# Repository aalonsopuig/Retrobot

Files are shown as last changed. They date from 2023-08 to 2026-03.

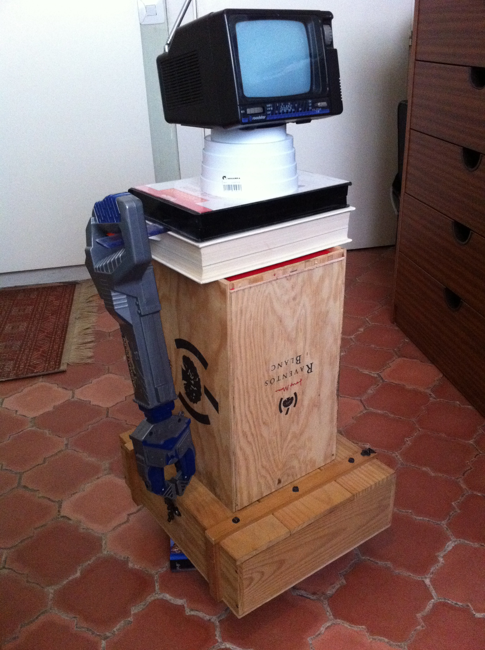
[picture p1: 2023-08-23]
Media/Imagen 343.jpg

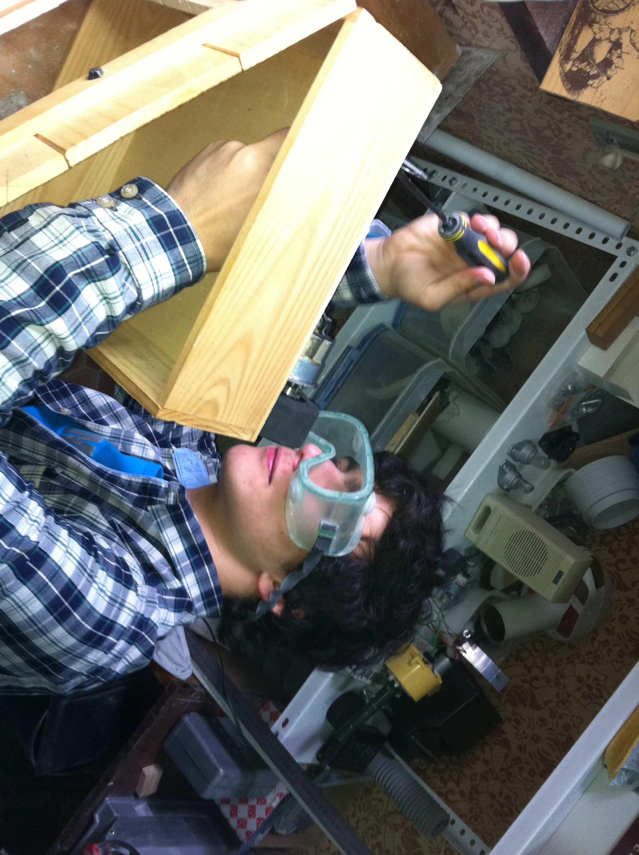
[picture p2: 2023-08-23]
Media/Imagen 345.jpg

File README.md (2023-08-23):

# Retrobot
 Por Alejandro Alonso y Manuel Alonso. 
 Julio 2011. 
 
Este fue un robot que hice para divertirme con mi sobrino. El objetivo era construir un robot con productos de principios de los 80. Para ello conseguimos un ordenador de los años 80 (Sinclair ZX-81) y otros componentes de eBay.
El robot pudo moverse, reproducir algunas canciones de esa época (grabadas en cinta de cassette y bailar mientras agitaba una maraca con su brazo izquierdo. También tenía un brazo derecho con una pinza extensible.
Fue presentado por primera vez en Campus Party 2011, evento que se realizaba en Valencia (España) para jóvenes aficionados a las tecnologías.

Retrobot_noticia

El centro del robot es un ordenador Sinclair ZX-81 original de los años 80, al cual se le ha conectado una tarjeta llamada interfaz (ExpansionCard) de diseño mío. Esta tarjeta contiene un microcontrolador Microchip PIC16F876, se conecta al puerto de expansión (bus) del ZX81 y permite a este acceder a todos los dispositivos del robot vía puerto I2C, así como mover los diferentes motores y actuadores del robot gracias a un driver incorporado en la tarjeta interfaz (ExpansionCard)
Nota: En el estado actual del proyecto, la tarjeta de interfaz está programada para controlar todo el robot y no hace de interfaz. Por tanto el software que se incluye en este repositorio solo hace esta función y el ZX81 no realiza ninguna función. Esto se debe a que el deseo de mostrar el robot moviéndose en Campus Party hizo que tuviese que recortar los tiempos, consiguiendo que el robot se moviese, pero sin conseguir el objetivo final, que era controlar el robot desde el ZX81 (objetivo pendiente que quizá algún día me anime a hacer)
Este es el el esquema general del robot:

Retrobot_aquitectura

Es este video puede verse el robot en acción en CampusParty 2011: https://www.youtube.com/watch?v=pIfZhs_rKEg

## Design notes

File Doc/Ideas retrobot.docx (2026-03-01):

# Ideas retrobot

Monitor es la cabeza

Zx81 el pecho

Muchas luces de colores

Brazo robotico

Sensores todo nada de infrarrojos distancia o pir

Base movil con ruedas y rueda loca

Si conseguimos sacar un puerto serie o I2C podriamos comunicarnos con una skypic plus o la que sea para enviarla ordenes y que ella se ocupe de comunicar con todas las funciones digitales o analogicas del cuerpo. Claro que entonces no se justifica tener un zx81

Ver los apuntes que tengo sobre los dos robots construidos con un zx81

Usar solo componentes existentes como tarde en los años 90

Usar sensores sharp GP2D15 fijado a 24cm. 15€

Usar sensor PIR delante pero metido en tubo para detectar una persona delante y hablar. 9€

Si hacemos una tarjeta interfaz i2c, podriamos poner montones de sensores conectados, tales como el capacitivo, mejores sensores de distancias, drivers, etc

Robot social que se acerca a personas y les dice cosas (usar tarjeta de voz digitalizada que tengo) como la temperatura que hace, si ha bebido o las caricias detectadas. En pantalla mostraria informacion escrita o expresiones emocionales

Para el I2C podemos usar un chip PCF8584. Más datos aquí: http://www.rwapservices.co.uk/ZX80_ZX81/forums/i2c-t412.html

Tarjeta conectada al ZX81 con el adaptador I2C, expansor de puertos, driver para luces, control servos, regulador de tensión, conversor A/D y sensor temperatura

Maracas

Iluminacion azul zx81 desde el interior del cuello

Antenas luminosas de Manolo para poner fuera de cascos

Efecto fibra de carbono

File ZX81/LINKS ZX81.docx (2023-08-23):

# LINKS ZX81

- Blog: http://www.elspectrumhoy.es
- Generador de WAVs: http://www.zx81stuff.org.uk/zx81/tapeutils/overview.html
- Soft, carátulas, pantallas, etc: http://www.zx81stuff.org.uk/zx81/indexframes.html
- Soft a tope: http://www.imarshall.karoo.net/zx81/
- Emuladores y .p files: http://www.zx81.nl/
- Varios en wav: http://personales.com/espana/alicante/todoa8bits/sinclair_CARGA.htm
- Manuales y documentos para parar un tren: http://www.worldofspectrum.org/documentation.html
- Solución video negro con televisores modernos: http://www.speccy.org/trastero/cosas/JL/zx81(2)/ZX81-video.html
- Inversor de video: http://www.user.dccnet.com/wrigter/index_files/zxinverter.htm
- Sacar la línea de video compuesto: http://www.zonadepruebas.com/modules/newbb/viewtopic.php?topic_id=11496&forum=2&post_id=112436
- Mucho soft gráfico: http://www.pictureviewerpro.com/hosting/zx81/fredn.htm
- Ingente info de hardware y soft: http://k1.dyndns.org/Vintage/Sinclair/80/Sinclair%20ZX81/
- ZX81 Speech synthesis: http://web.inter.nl.net/hcc/davies/mvzx81.html
- Sobre el conector para módulos externos. Este es el 5645169-2 para ISA, pero es compatible cortándolo: http://ie.farnell.com/edac/395-098-520-350/card-edge-connector-socket-98pos/dp/5389781, http://ca.digikey.com/1/1/2063590-conn-sec-ii-49pos-100-c-l-5645169-2.html, http://www.almita-connectors.com/connector/isa-connectors.html, http://www.kemax.com.tw/detail/284166/284166.html, http://parts.digikey.ca/1/1/107613-conn-sec-ii-30pos-100c-l-1-530843-8.html

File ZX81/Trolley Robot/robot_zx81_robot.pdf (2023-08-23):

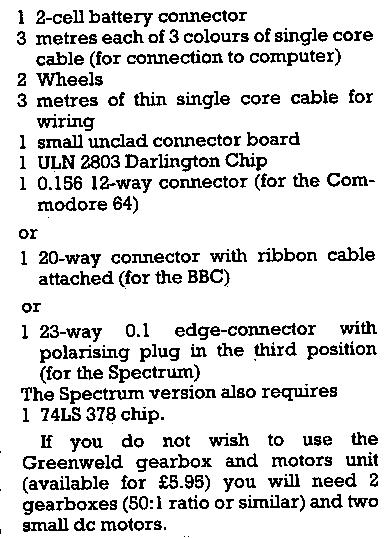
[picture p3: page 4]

Commodore:

10 POKE 59459,255: PO=59471: REM PET 10 POKE 56579,255: PO=56577: REM CBM64 10 POKE 37138,255: PO=37136: REM VIC20 20 DIM B(100), T(100)
30 N=0: TI$="000000"
40 POKE PO, 0
100 GET A$
110 IF A$="" THEN 100
120 IF A$=" " THEN K=0
130 IF A$="R" THEN K=1
140 IF A$="L" THEN K=2
150 IF A$="F" THEN K=3
160 IF A$="G" THEN 300
170 N=N+1: IF N>100 THEN 300 180 B(N)=K
190 T(N)=TI
200 POKE PO,0
220 FOR J=1 TO 200: NEXT
230 POKE PO,K
240 GOTO 100
300 TI$="000000"
310 POKE PO,0
320 FOR M=1 TO N
330 IF TI<T(M) THEN 330
340 POKE PO,0
350 FOR J=1 TO 200: NEXT
360 POKE PO,B(M)
370 NEXT M

BBC:

10 DIM B(100)
20 DIM T(100)
30 N=0: TIME=0
40 J=0: K=0
50 PORT=&FE60: ?&FE62=3
100 A$=INKEY$(0)
130 IF A$="" THEN 100
140 IF A$=" " THEN K=0
150 IF A$="L" THEN K=2
160 IF A$="R" THEN K=1
170 IF A$="F" THEN K=3
180 IF A$="G" THEN 300
190 N=N+1
200 B(N)=K•
210 T(N)=TIME
220 ?PORT=0
230 J=INKEY(25)
240 ?PORT=K
260 GOTO 100
300 TIME=0
310 FOR M=1 TO N
320 REPEAT UNTIL TIME > T(M) 330 ?PORT=0
340 K=INKEY(25)
350 ?PORT=B(M)
360 NEXT M

Sinclair:

10 DIM b(100)
20 DIM t(100)
30 LET i=0: LET n=0: LET j=0: LET k=0 100 LET a$=INKEY$
110 LET i=i+1
120 IF i<j THEN GO TO 100
130 IF a$="" THEN GO TO 100 140 IF a$=" " THEN LET k=0 150 IF a$="l" THEN LET k=2 160 IF a$="r" THEN LET k=1 170 IF a$="f" THEN LET k=3 180 IF a$="g" THEN GO TO 300 190 LET n=n+1
200 LET b(n)=k
210 LET t(n)=i
220 OUT 255,0
230 FOR j=1 TO 100: NEXT j 240 OUT 255,k
250 LET j=1

260 GO TO 100
300 LET i=0
310 FOR m=1 TO n
320 FOR j=1 TO t(m): NEXT j 330 OUT 255,0
340 FOR j=1 TO 100: NEXT j 350 OUT 255,b(m)
360 NEXT m
370 OUT 255,0

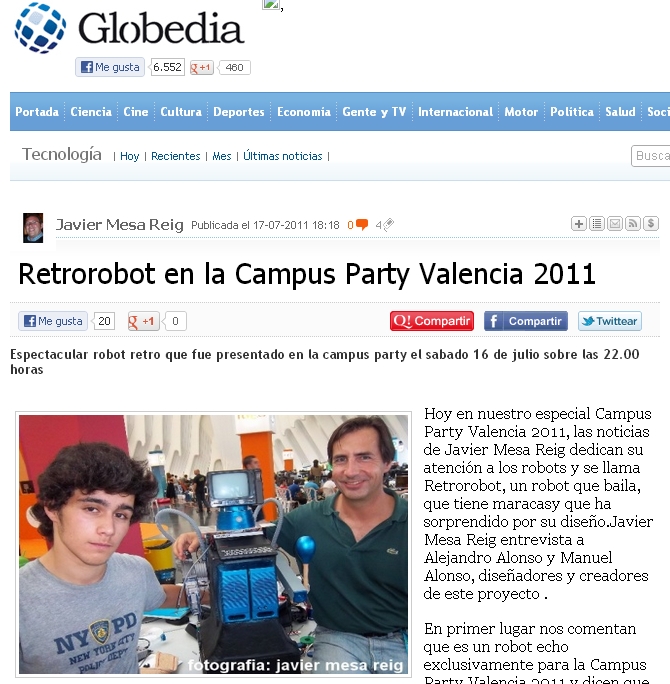
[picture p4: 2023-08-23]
Media/Retrobot_noticia.jpg

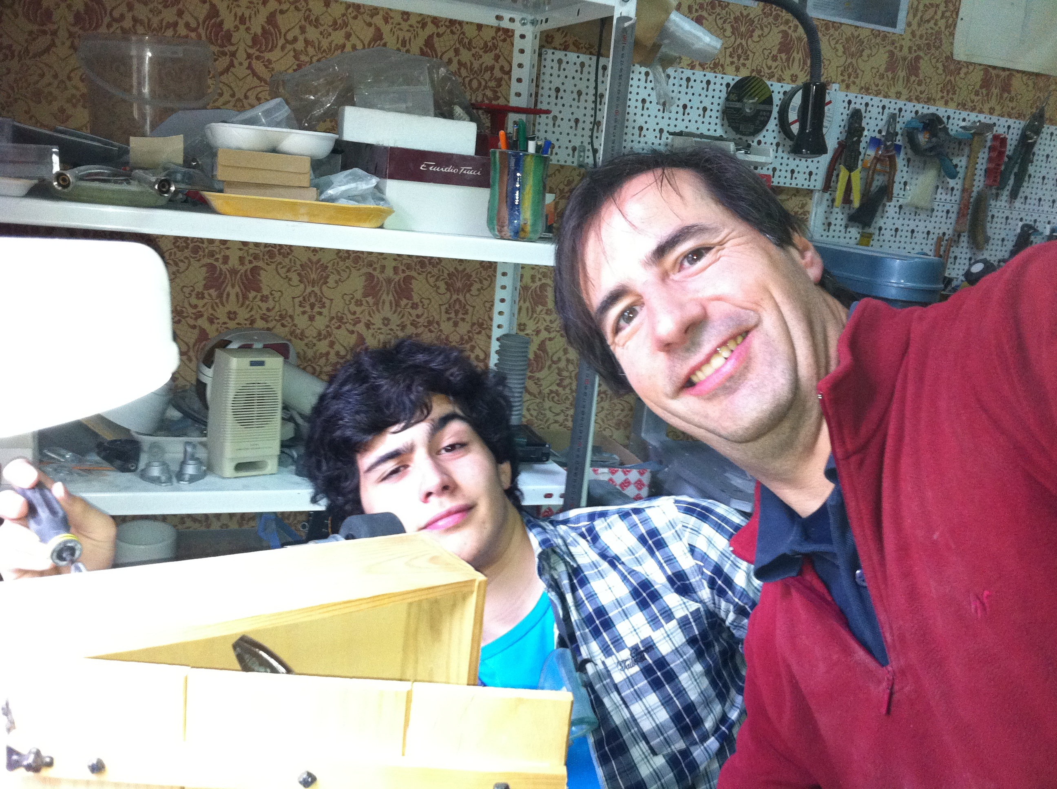
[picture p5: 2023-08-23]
Media/Imagen 346.jpg

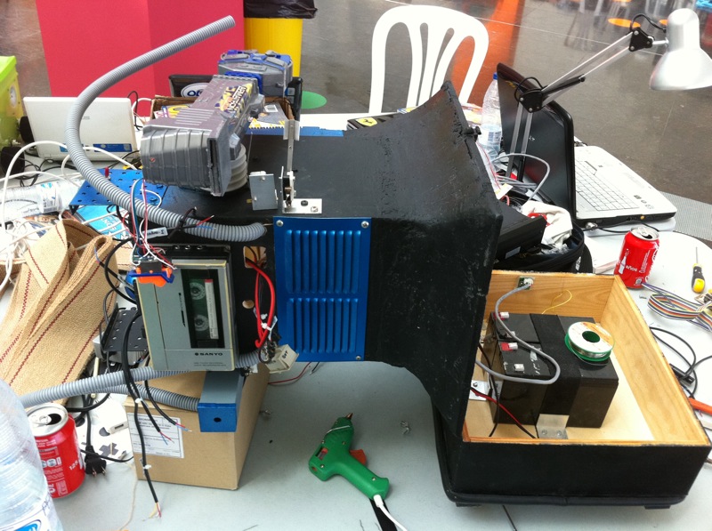
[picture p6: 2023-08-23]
Media/Foto 16-07-11 15 34 29.jpeg

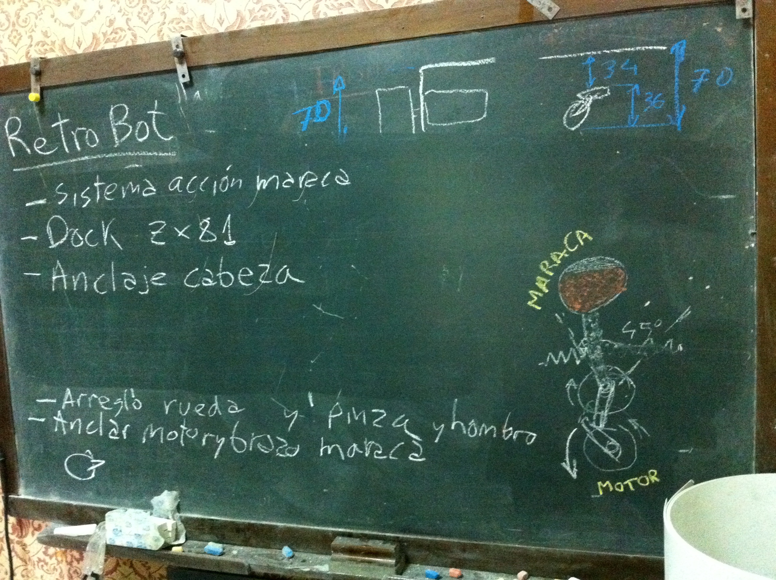
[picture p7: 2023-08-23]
Media/Imagen 130.jpg

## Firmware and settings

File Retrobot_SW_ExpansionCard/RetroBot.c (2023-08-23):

/*
PROGRAM:    RetroBot
DEVELOPER:  LIEBANA Design
DATE:       July 2011
Purpose:    This program is loaded in the ZX81 Expansion Card
            and control the interface.

Pinout:
RA0   IN    Not connected
RA1   OUT   ZX81 Wait signal
RA2   IN    ZX81 Direction of data 
RA3   OUT   Relay control
RA4   IN    Not connected
RA5   IN    PIR signal
RB0   IN    ZX81 ready signal      
RB1   I/O   Data Line 1 
RB2   I/O   Data Line 2
RB3   I/O   Data Line 3
RB4   I/O   Data Line 4
RB5   I/O   Data Line 5
RB6   I/O   Data Line 6
RB7   I/O   Data Line 7
RC0   IN    Not connected   
RC1   OUT   PWM2 for motors   
RC2   OUT   PWM1 for motors 
RC3         I2C. SCL
RC4         I2C. SDA
RC5   I/O   Data Line 0
RC6   OUT   Led
RC7   IN    Not connected

I/O Expansion Port Pinout:

A0    OUT   S1M1
A1    OUT   S2M1
A2    OUT   S1M2
A3    OUT   S2M2
A4    OUT   S1M3
A5    OUT   S2M3
A6    OUT   S1M4
A7    OUT   S2M4 
B0    OUT   S1M5
B1    OUT   S2M5
B2    OUT   S1M6
B3    OUT   S2M6
B4    OUT   S1M7
B5    OUT   S2M7
B6    OUT   S1M8
B7    OUT   S2M8


*/
// LIBRARIES
#include "RetroBot.h"
#include "LM75.h"             //Library for LM75 I2C Temperature Sensor 
#include "MCP23016.h"         //MCP23016 Chip (16 bit IO expander via I2C)
#include "SRF02.h"            //SRF02 Device (Sonar via I2C)

//I2C address
#DEFINE  LM75Address      0x9E  //Temperature sensor
#DEFINE  SRF02Address     0xE0  //Sonar sensor

//Pins assignment
#DEFINE  ZX81_WAIT       PIN_A1   //Active low. stop ZX81 clock during a transfer
#DEFINE  ZX81_DIR        PIN_A2   //Data dir. 1:ZX81->ExpCard, 0:ExpCard->ZX81
#DEFINE  Relay           PIN_A3   //Relay control
#DEFINE  PIR             PIN_A5   //PIR signal
#DEFINE  ZX81_READY      PIN_B0   //Indicate ZX81 is ready for a read or write
#DEFINE  DataLine0       PIN_C5   //Data line 0
#DEFINE  LED             PIN_C6   //Test led

//Motors control
#DEFINE  FORWARD         255      //Forward for motors
#DEFINE  BACKWARD          0      //Backward for motors
#DEFINE  STOP            128      //Stop for motors
#DEFINE  ACTIVATE          0      //ACTIVATE for motors
#DEFINE  OPEN            255      //OPEN for motors
#DEFINE  CLOSE             0      //CLOSE for motors
#DEFINE  UP              255      //Move up for motors
#DEFINE  DOWN              0      //Move down for motors

#DEFINE  MaxDuty 800     //Maximum value of Duty Cycle (100%)
#DEFINE  MinDuty 200     //Duty were the motor stops for sure

//Motor assignment
#DEFINE  Maraca            1      //Motor assigned to Maraca
#DEFINE  Hand_R            2      //Motor assigned to Hand of right arm
#DEFINE  Arm_R             3      //Motor assigned to right arm
#DEFINE  Light_R           4      //Motor assigned to light of right arm
#DEFINE  Wheel_R           5      //Motor assigned to right wheel
#DEFINE  Wheel_L           6      //Motor assigned to left wheel
#DEFINE  Shoulder_R        7      //Motor assigned to shoulder of right arm
#DEFINE  Shoulder_L        8      //Motor assigned to shoulder of left arm


//Counters
#DEFINE  MaxCounters    2     //Number of multipurpose counters
#DEFINE  AutoNavFwd     0     //counter for allowing forward movement
#DEFINE  Dance          1     //counter for dance times

#DEFINE  MaxAutoNavFwd   381     //x13.1= 5s aprox
#DEFINE  MaxDance        763     //x13.1= 10s aprox


byte  Temperature=0;             //Temperature of the card
byte  Distance=0;                //Value in cm of distance to obstacle 8bit
int1  PIRStatus=FALSE;           //Status of PIR sensor

int1  AutoNavMode=FALSE;      //Indicate if auto navigation mode is active
int16 Counter[MaxCounters];         //Multipurpose counters incremented by interrupt

int16  i;                            //Used for local FOR loops



#INT_TIMER3
//Timer3 Interrupt. Used for several multipurpose counters Counter[]
//overflows every 13.1ms incrementing all counters by 1
void Timer3_isr() 
{
   byte NumCounter;

   for(NumCounter=0;NumCounter<MaxCounters;NumCounter++)
      Counter[NumCounter]++;
}


void InitGeneralPurposeCounters() 
//Put all general purpose counters to 0
{
   byte NumCounter;

   for(NumCounter=0;NumCounter<MaxCounters;NumCounter++)
      Counter[NumCounter]=0;
}   

void Blink (byte blinks)
//Blinks card led
{
   byte i;
   for(i=1;i<=blinks;i++) {
      output_high(LED);
      delay_ms(100);
      output_low(LED);
      delay_ms(100);              
   }
}


void SetMotor (byte MotorNum, Direction)
//Control the direction of the 8 motors
//Direction 128:Stop, >128:Forward, <128:backwards
{
   switch (MotorNum) {
      case 1:
         if(Direction<128){
            MCP23016_output_high (MCP23016_PIN_A0);
            MCP23016_output_low  (MCP23016_PIN_A1);
         }
         if(Direction>128){
            MCP23016_output_low  (MCP23016_PIN_A0);
            MCP23016_output_high (MCP23016_PIN_A1);
         }
         if(Direction==128){
            MCP23016_output_low (MCP23016_PIN_A0|MCP23016_PIN_A1);         
         }
         break;
      case 2:
         if(Direction<128){
            MCP23016_output_high (MCP23016_PIN_A2);
            MCP23016_output_low  (MCP23016_PIN_A3);
         }
         if(Direction>128){
            MCP23016_output_low  (MCP23016_PIN_A2);
            MCP23016_output_high (MCP23016_PIN_A3);
         }
         if(Direction==128){
            MCP23016_output_low (MCP23016_PIN_A2|MCP23016_PIN_A3);         
         }
         break;
      case 3:
         if(Direction<128){
            MCP23016_output_high (MCP23016_PIN_A4);
            MCP23016_output_low  (MCP23016_PIN_A5);
         }
         if(Direction>128){
            MCP23016_output_low  (MCP23016_PIN_A4);
            MCP23016_output_high (MCP23016_PIN_A5);
         }
         if(Direction==128){
            MCP23016_output_low (MCP23016_PIN_A4|MCP23016_PIN_A5);         
         }
         break;
      case 4:
         if(Direction<128){
            MCP23016_output_high (MCP23016_PIN_A6);
            MCP23016_output_low  (MCP23016_PIN_A7);
         }
         if(Direction>128){
            MCP23016_output_low  (MCP23016_PIN_A6);
            MCP23016_output_high (MCP23016_PIN_A7);
         }
         if(Direction==128){
            MCP23016_output_low (MCP23016_PIN_A6|MCP23016_PIN_A7);         
         }
         break;
      case 5:
         if(Direction<128){
            MCP23016_output_high (MCP23016_PIN_B0);
            MCP23016_output_low  (MCP23016_PIN_B1);
         }
         if(Direction>128){
            MCP23016_output_low  (MCP23016_PIN_B0);
            MCP23016_output_high (MCP23016_PIN_B1);
         }
         if(Direction==128){
            MCP23016_output_low (MCP23016_PIN_B0|MCP23016_PIN_B1);         
         }
         break;
      case 6:
         if(Direction<128){
            MCP23016_output_high (MCP23016_PIN_B2);
            MCP23016_output_low  (MCP23016_PIN_B3);
         }
         if(Direction>128){
            MCP23016_output_low  (MCP23016_PIN_B2);
            MCP23016_output_high (MCP23016_PIN_B3);
         }
         if(Direction==128){
            MCP23016_output_low (MCP23016_PIN_B2|MCP23016_PIN_B3);         
         }
         break;
      case 7:
         if(Direction<128){
            MCP23016_output_high (MCP23016_PIN_B4);
            MCP23016_output_low  (MCP23016_PIN_B5);
         }
         if(Direction>128){
            MCP23016_output_low  (MCP23016_PIN_B4);
            MCP23016_output_high (MCP23016_PIN_B5);
         }
         if(Direction==128){
            MCP23016_output_low (MCP23016_PIN_B4|MCP23016_PIN_B5);         
         }
         break;
      case 8:
         if(Direction<128){
            MCP23016_output_high (MCP23016_PIN_B6);
            MCP23016_output_low  (MCP23016_PIN_B7);
         }
         if(Direction>128){
            MCP23016_output_low  (MCP23016_PIN_B6);
            MCP23016_output_high (MCP23016_PIN_B7);
         }
         if(Direction==128){
            MCP23016_output_low (MCP23016_PIN_B6|MCP23016_PIN_B7);         
         }
         break;
      default:
         break; 
   }
}

void Dancer ()
// Activate audio cassette and dance with maraca
{

   Output_high(RELAY);            //Relay (Casete) signal on 
   SetMotor (Maraca, ACTIVATE);    //Activate maraca
   for (i=1;i<=8;++i) {
      SetMotor (Wheel_R, FORWARD);   
      SetMotor (Wheel_L, BACKWARD);   
      delay_ms (1000);  //Time of turn. Then stop
      SetMotor (Wheel_R, STOP);   
      SetMotor (Wheel_L, STOP);   
      delay_ms (1000);  //Time of turn. Then stop
      SetMotor (Wheel_R, BACKWARD);   
      SetMotor (Wheel_L, FORWARD);   
      delay_ms (1000);  //Time of turn. Then stop
      SetMotor (Wheel_R, STOP);   
      SetMotor (Wheel_L, STOP);   
   }
   Output_low(RELAY);            //Relay (Casete) signal off 
   SetMotor (Maraca, STOP);    //Activate maraca
   //Arm
   SetMotor (Arm_R, FORWARD);    //Extend Arm_R
   delay_ms(1000);
   SetMotor (Arm_R, STOP);    //Stop Arm_R
   delay_ms(1000);
   SetMotor (Arm_R, BACKWARD);    //Compress Arm_R
   delay_ms(1000);
   SetMotor (Arm_R, STOP);    //Stop Arm_R
}



///////////////////////////////////////////////////////////////////////////////
//////                                                                   //////
//////                          MAIN BODY                                //////
//////                                                                   //////
///////////////////////////////////////////////////////////////////////////////

void main()
{

   //Ports configuration
   set_tris_a (0b11110101);        //configure port A (See comments at header)
   set_tris_b (0b11111111);        //configure port B (See comments at header)
   set_tris_c (0b10100001);        //configure port C (See comments at header)
   
   Output_low(RELAY);            //Relay signal off 
   Output_low(LED);              //Led off
   Output_high(ZX81_WAIT);       //Non wait (Active low)


   //TIMERS CONFIGURATION
   setup_timer_3(T3_INTERNAL|T3_DIV_BY_1);   //Timer for multipurpose counters
   set_timer3(0);                            //ensure overflow every 13.1ms

   //PWM generation
   setup_timer_2(T2_DIV_BY_1,199,1);          // PWM 1 & 2 aprox 25KHz
   setup_ccp1(CCP_PWM);                      
   setup_ccp2(CCP_PWM);
   set_pwm1_duty(800);         
   set_pwm2_duty(500);         

   //General Purpose counters
   InitGeneralPurposeCounters();

   //ENABLE INTERRUPTS
   enable_interrupts(INT_TIMER3);   //Timer3 overflow
   enable_interrupts(GLOBAL);   


   //OTHER INITIAL SETUPS --------------------------------

   Blink(10);

   //I/O Espander port config . Do not move.
   MCP23016_Reg_Write(IODIR0, 0b00000000);
   MCP23016_Reg_Write(IODIR1, 0b00000000);
   

//   set_pwm1_duty(800);           //Duty cycle of Group 1 of motors 

AutoNavMode=TRUE;
//Output_high(RELAY);

   while (TRUE) { //MAIN LOOP

//      Temperature=LM75_TempRead(LM75Address);   //Get temperature
//      PIRStatus=Input(PIR);                     //Get PIR status
      Distance=SRF02_Distance_8(SRF02Address);         //Get Sonar range

/*delay_ms(1000);

If (Distance!=0) Blink(2);
*/
//If (PIRStatus) Blink(2);

   //Arm
/*   SetMotor (Shoulder_L, UP);    //Move up Shoulder_L
   delay_ms(6000);
   SetMotor (Shoulder_L, STOP);    //Stop Shoulder_L
   delay_ms(1000);
   SetMotor (Shoulder_L, DOWN);    //Move down Shoulder_L
   delay_ms(3000);
   SetMotor (Shoulder_L, STOP);    //Stop Shoulder_L
   delay_ms(2000);

*/


/*

            SetMotor (Wheel_R, FORWARD);   
            SetMotor (Wheel_L, FORWARD);   
            delay_ms (1000);  //Time of turn. Then stop
            SetMotor (Wheel_R, STOP);   
            SetMotor (Wheel_L, STOP);   


   //Arm
   SetMotor (Arm_R, FORWARD);    //Extend Arm_R
   delay_ms(1000);
   SetMotor (Arm_R, STOP);    //Stop Arm_R
   delay_ms(1000);
   SetMotor (Arm_R, BACKWARD);    //Compress Arm_R
   delay_ms(1000);
   SetMotor (Arm_R, STOP);    //Stop Arm_R
   delay_ms(1000);

   //Hand
   SetMotor (Hand_R, OPEN);    //Open hand
   delay_ms(1000);
   SetMotor (Hand_R, STOP);    //Stop hand
   delay_ms(1000);
   SetMotor (Light_R, ACTIVATE);    //Activate Light right arm
   delay_ms(1000);
   SetMotor (Light_R, STOP);    //STOP Light right arm
   SetMotor (Hand_R, CLOSE);    //Close hand
   delay_ms(1000);
   SetMotor (Hand_R, STOP);    //Stop hand
   delay_ms(1000);

   //Maraca
   SetMotor (Maraca, ACTIVATE);    //Activate maraca
   delay_ms(2000);
   SetMotor (Maraca, STOP);    //Stop maraca
   delay_ms(4000);
*/
      //Activación audio
/*      SetRelay(TRUE);
      delay_ms(2000);
      SetRelay(FALSE);
      delay_ms(4000);
*/     

//Counter[Dance]=0;

      if (Counter[Dance]>MaxDance){
         Dancer ();
         Counter[Dance]=0;
      }

      if(AutoNavMode) {
         if(((Distance<50)&&(Distance>0))||(Counter[AutoNavFwd]>MaxAutoNavFwd)) { 
         //Obstacle in front or too much time going ahead. Turn a bit
            SetMotor (Wheel_R, STOP);   
            SetMotor (Wheel_L, STOP);   
            delay_ms (100);
            SetMotor (Wheel_R, FORWARD);   
            SetMotor (Wheel_L, BACKWARD);   
            delay_ms (1000);  //Time of turn. Then stop
            SetMotor (Wheel_R, STOP);   
            SetMotor (Wheel_L, STOP);   
            Counter[AutoNavFwd]=0;
         }
         else {                             //No obstacle. Go forward
            SetMotor (Wheel_R, FORWARD);   
            SetMotor (Wheel_L, FORWARD);   
         }
      }

   } //End While MAIN LOOP

}  //End Program
